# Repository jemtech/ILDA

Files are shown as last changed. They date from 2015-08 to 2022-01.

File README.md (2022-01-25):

# ILDA
This project is a DAC ([digital to analog converter](https://en.wikipedia.org/wiki/Digital-to-analog_converter)) which generates six [differential signals](https://en.wikipedia.org/wiki/Differential_signaling) based on the ILDA ([International Laser Display Association](http://www.laserist.org/)) [ISP-DB25 standard](http://www.laserist.org/StandardsDocs/ILDA_ISP99_rev002.pdf).
Two signals for the X and Y axis (-10V to +10V), four signals for the channels red, green and blue and one custom colour (0V to +5V).
The DAC is controlled via [SPI](https://en.wikipedia.org/wiki/Serial_Peripheral_Interface_Bus). In this case the software is written for a "Raspberry Pi", but any other controller can be used.

This project contains two sections:

1. Hardware: In this section you find a 16bit 6ch DAC for ILDA. Reaching 22kpps (measured with [ILDA Test Pattern](http://www.laserist.org/StandardsDocs/ILDA_TestPattern95_rev002.pdf), theoretical up to 400kpps) limited by the controling "Raspberry Pi". It is resulting in a resolution of 4294967296 positions (~4295 megapixels).
The asynchronous LDAC update pin at the DAC, immediately updates the DAC register with the contents of the input register, so all outputs change at the same time and can be synchronised with an external clock.
2. Software: C based software to control the ILDA-DAC with a "Raspberry Pi". Supports all Files based on the [ILDA Image Data Transfer Format](http://www.laserist.org/StandardsDocs/ILDA_IDTF14_rev011.pdf).

## Hardware
The hardware is designed with [KiCad](http://kicad.org/).
"ILDA/hardware/kicad/"
Using 5 channels (x,y,r,g,b) with 16bit at 50MHz SPI speed the DAC reaches theoretically 400kpps (50000KHz ÷ (5×24bit) = 416kpps).

## Software
### Dependencies
[Wiring Pi](http://wiringpi.com/).
### Installation
1. Install "Wiring Pi". Then follow the instructions on [Wiring Pi](http://wiringpi.com/).
2. Download this project to your "Raspberry Pi".
3. Change to the "ILDA/software/raspberrypi/" folder.
4. Run "make".

Now you can run the software with "sudo ./ildaNode".

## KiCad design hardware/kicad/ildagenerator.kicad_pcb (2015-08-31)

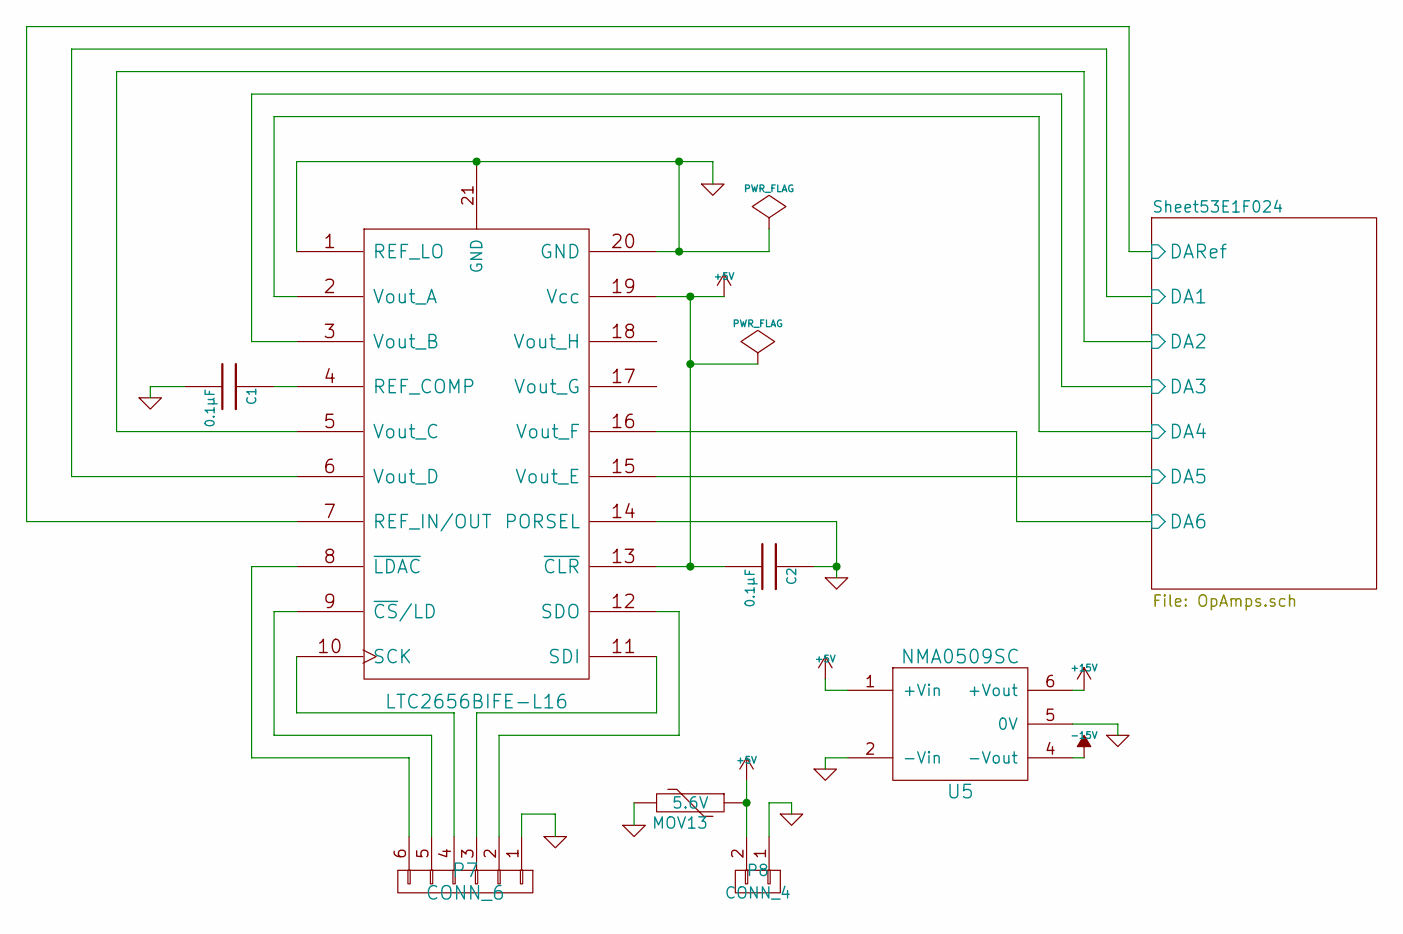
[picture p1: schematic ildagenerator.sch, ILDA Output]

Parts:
C1, C2: 0.1µF; C_0805_HandSoldering
MOV13: 5.6V; R_1206_HandSoldering
P7: CONN_6; Pin_Header_Straight_1x06
P8: CONN_4; Pin_Header_Straight_1x02
U1: LTC2656BIFE-L16
U5: NMA0509SC; NMA_5V_12V_15V_Series

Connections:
+5V: C2.2, MOV13.1, P8.2, U1.13 (~CLR), U1.19 (Vcc), U5.1 (+Vin)
+15V: U5.6 (+Vout); also elsewhere on the board
-15V: U5.4 (-Vout); also elsewhere on the board
/Sheet53E1F024/DA1: U1.6 (Vout_D); also elsewhere on the board
/Sheet53E1F024/DA2: U1.5 (Vout_C); also elsewhere on the board
/Sheet53E1F024/DA3: U1.3 (Vout_B); also elsewhere on the board
/Sheet53E1F024/DA4: U1.2 (Vout_A); also elsewhere on the board
/Sheet53E1F024/DA5: U1.15 (Vout_E); also elsewhere on the board
/Sheet53E1F024/DA6: U1.16 (Vout_F); also elsewhere on the board
/Sheet53E1F024/DARef: U1.7 (REF_IN/OUT); also elsewhere on the board
GND: C1.2, C2.1, MOV13.2, P7.1, P8.1, U1.1 (REF_LO), U1.14 (PORSEL), U1.20 (GND), U1.21 (GND), U5.2 (-Vin), U5.5 (0V); also elsewhere on the board
unnamed: C1.1, U1.4 (REF_COMP)
unnamed: P7.2, U1.12 (SDO)
unnamed: P7.3, U1.11 (SDI)
unnamed: P7.4, U1.10 (SCK)
unnamed: P7.5, U1.9 (~CS~/LD)
unnamed: P7.6, U1.8 (~LDAC)

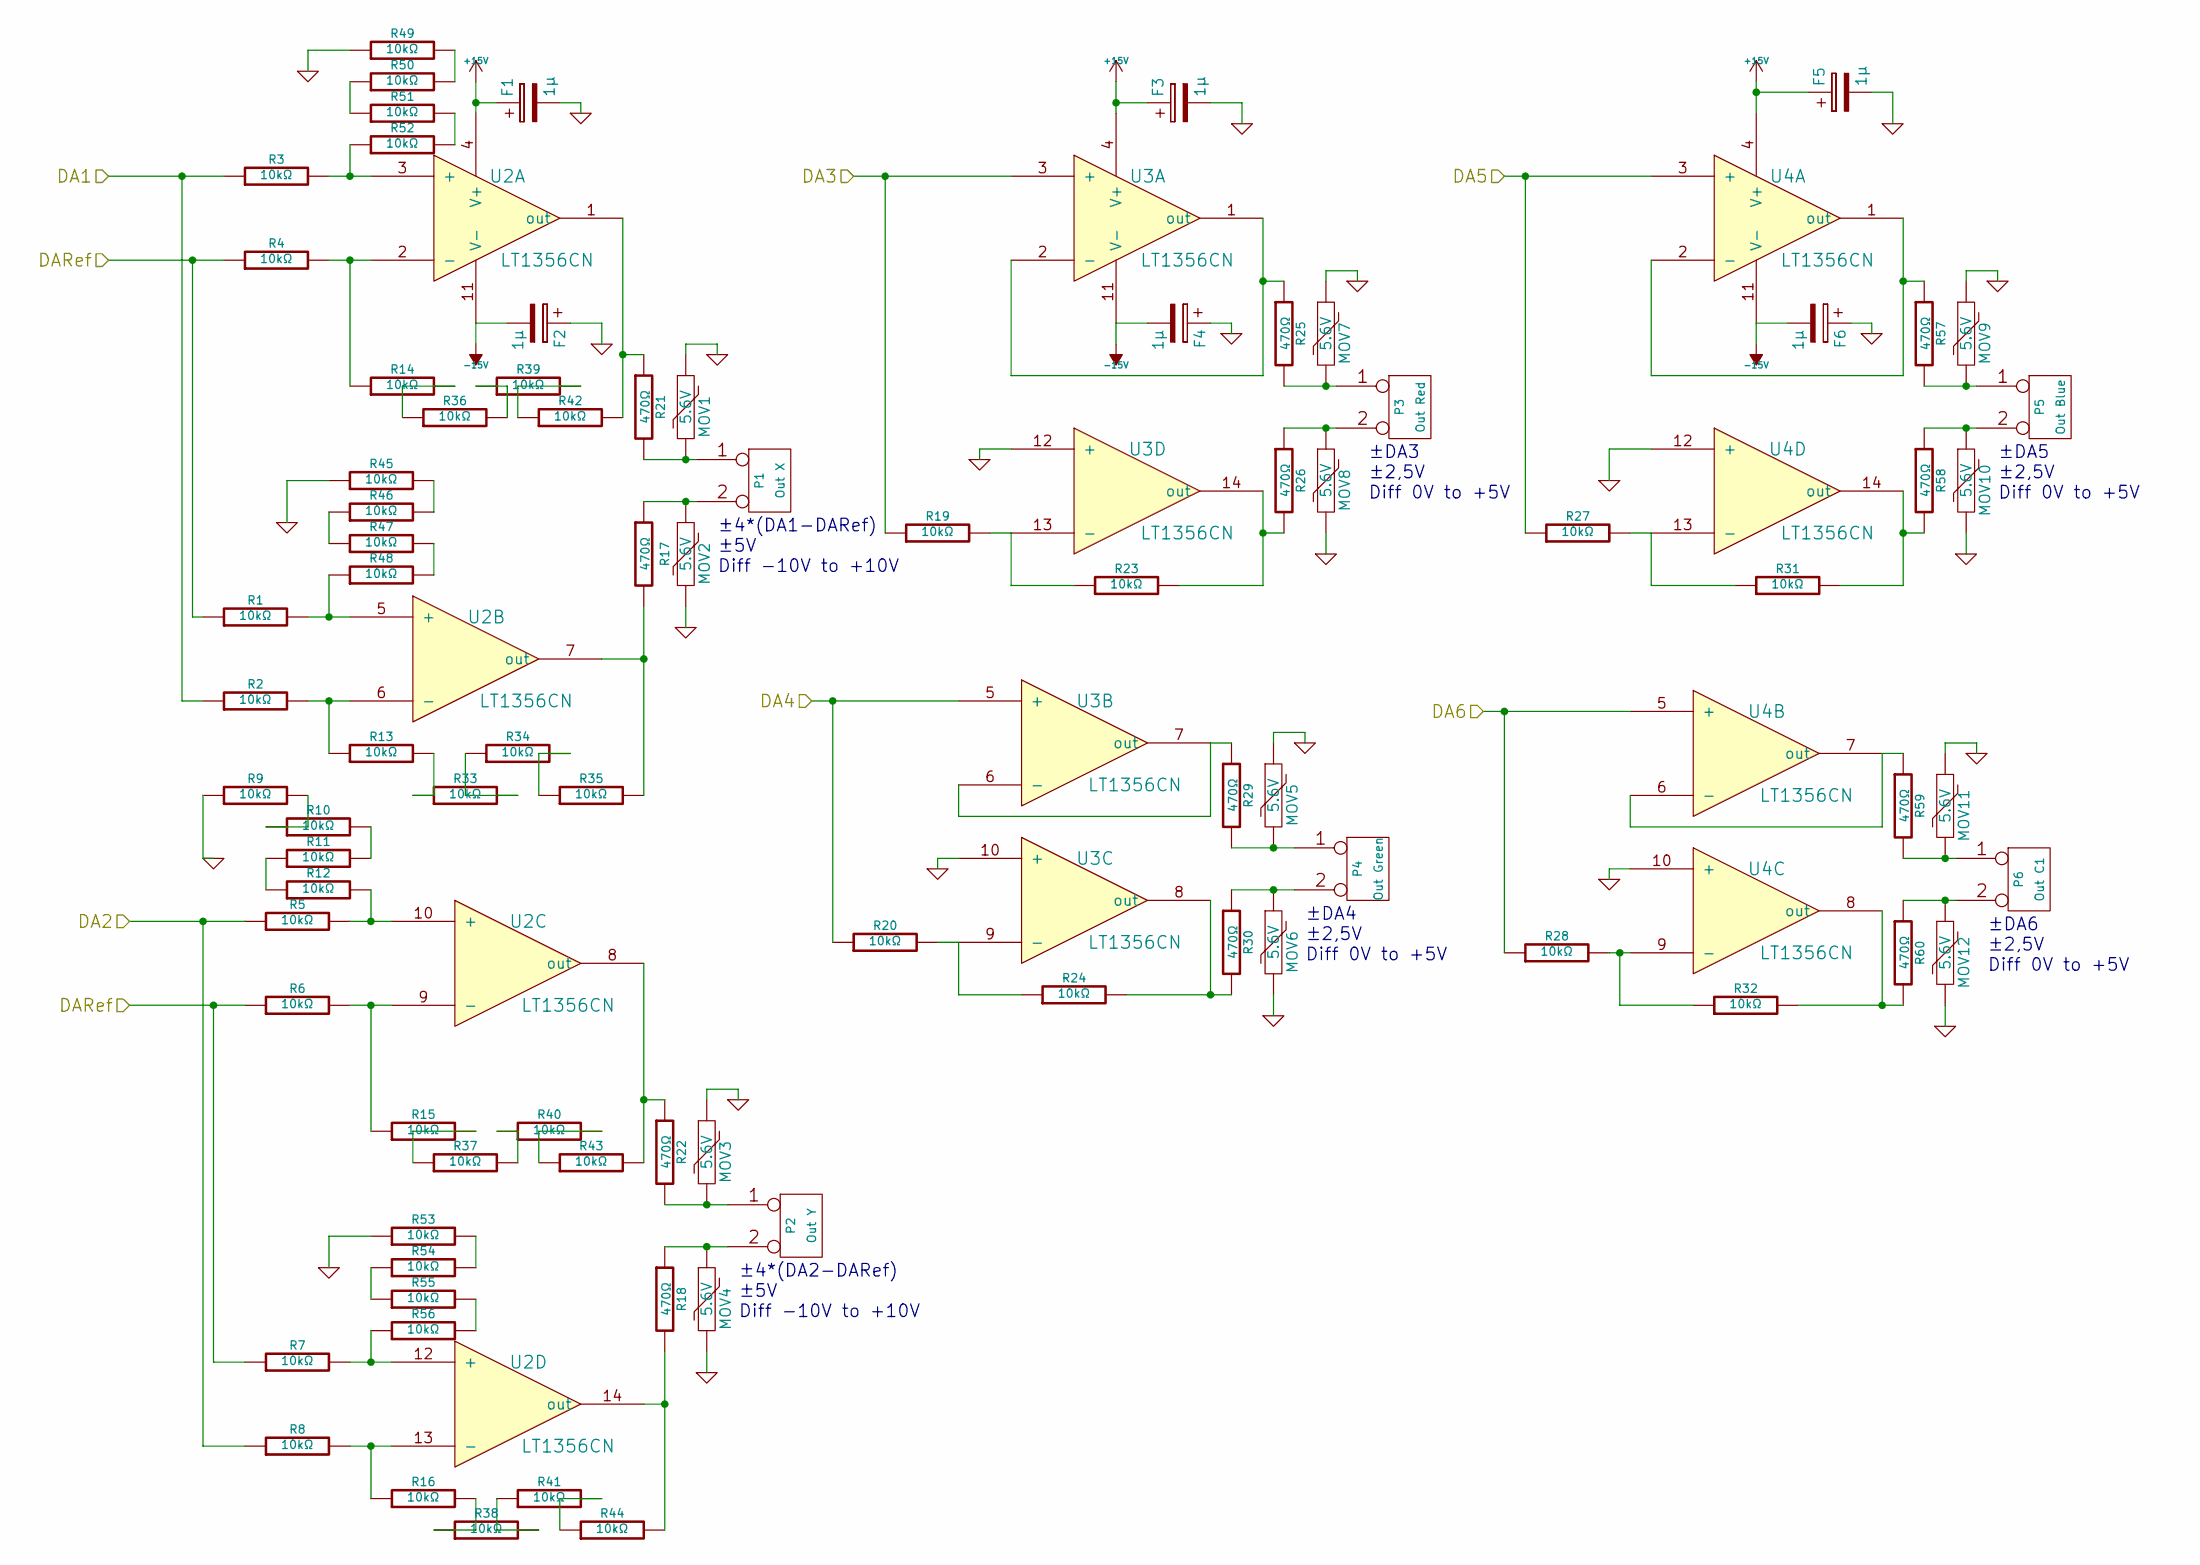
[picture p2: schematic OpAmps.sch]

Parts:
F1, F2, F3, F4, F5, F6: 1µ; TantalC_SizeB_EIA-3528_HandSoldering
MOV1, MOV2, MOV3, MOV4, MOV5, MOV6, MOV7, MOV8, MOV9, MOV10, MOV11, MOV12: 5.6V; R_1206_HandSoldering
P1: Out X
P2: Out Y
P3: Out Red
P4: Out Green
P5: Out Blue
P6: Out C1
R1, R2, R3, R4, R5, R6, R7, R8, R9, R10, R11, R12, R13, R14, R15, R16, R20, R24, R33, R34, R35, R36, R37, R38, R39, R40, R41, R42, R43, R44, R45, R46, R47, R48, R49, R50, R51, R52, R53, R54, R55, R56: 10kΩ; R_0603_HandSoldering
R17, R18, R21, R22: 470Ω; R_0603_HandSoldering
R19, R23, R27, R28, R31, R32: 10kΩ
R25, R26, R29, R30, R57, R58, R59, R60: 470Ω
U2, U3, U4: LT1356CN

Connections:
+15V: F1.1, F3.1, F5.1, U2.4 (V+), U3.4 (V+), U4.4 (V+); also elsewhere on the board
-15V: F2.2, F4.2, F6.2, U2.11 (V-), U3.11 (V-), U4.11 (V-); also elsewhere on the board
/Sheet53E1F024/DA1: R2.1, R3.1; also elsewhere on the board
/Sheet53E1F024/DA2: R5.1, R8.1; also elsewhere on the board
/Sheet53E1F024/DA3: R19.1, U3.3 (+); also elsewhere on the board
/Sheet53E1F024/DA4: R20.1, U3.5 (+); also elsewhere on the board
/Sheet53E1F024/DA5: R27.1, U4.3 (+); also elsewhere on the board
/Sheet53E1F024/DA6: R28.1, U4.5 (+); also elsewhere on the board
/Sheet53E1F024/DARef: R1.1, R4.1, R6.1, R7.1; also elsewhere on the board
GND: F1.2, F2.1, F3.2, F4.1, F5.2, F6.1, MOV1.1, MOV2.2, MOV3.1, MOV4.2, MOV5.1, MOV6.2, MOV7.1, MOV8.2, MOV9.1, MOV10.2, MOV11.1, MOV12.2, R9.1, R45.1, R49.1, R53.1, U3.10 (+), U3.12 (+), U4.10 (+), U4.12 (+); also elsewhere on the board
unnamed: MOV1.2, P1.1, R21.2
unnamed: MOV2.1, P1.2 (PM), R17.1
unnamed: MOV3.2, P2.1, R22.2
unnamed: MOV4.1, P2.2 (PM), R18.1
unnamed: MOV5.2, P4.1, R29.2
unnamed: MOV6.1, P4.2 (PM), R30.1
unnamed: MOV7.2, P3.1, R25.2
unnamed: MOV8.1, P3.2 (PM), R26.1
unnamed: MOV9.2, P5.1, R57.2
unnamed: MOV10.1, P5.2 (PM), R58.1
unnamed: MOV11.2, P6.1, R59.2
unnamed: MOV12.1, P6.2 (PM), R60.1
unnamed: R1.2, R48.1, U2.5 (+)
unnamed: R3.2, R52.1, U2.3 (+)
unnamed: R9.2, R10.1
unnamed: R10.2, R11.2
unnamed: R11.1, R12.1
unnamed: R5.2, R12.2, U2.10 (+)
unnamed: R2.2, R13.1, U2.6 (-)
unnamed: R13.2, R33.1
unnamed: R4.2, R14.1, U2.2 (-)
unnamed: R14.2, R36.1
unnamed: R6.2, R15.1, U2.9 (-)
unnamed: R15.2, R37.1
unnamed: R8.2, R16.1, U2.13 (-)
unnamed: R16.2, R38.1
unnamed: R17.2, R35.2, U2.7 (out)
unnamed: R18.2, R44.2, U2.14 (out)
unnamed: R19.2, R23.1, U3.13 (-)
unnamed: R20.2, R24.1, U3.9 (-)
unnamed: R21.1, R42.2, U2.1 (out)
unnamed: R22.1, R43.2, U2.8 (out)
unnamed: R23.2, R26.2, U3.14 (out)
unnamed: R24.2, R30.2, U3.8 (out)
unnamed: R25.1, U3.1 (out), U3.2 (-)
unnamed: R27.2, R31.1, U4.13 (-)
unnamed: R28.2, R32.1, U4.9 (-)
unnamed: R29.1, U3.6 (-), U3.7 (out)
unnamed: R31.2, R58.2, U4.14 (out)
unnamed: R32.2, R60.2, U4.8 (out)
unnamed: R33.2, R34.1
unnamed: R34.2, R35.1
unnamed: R36.2, R39.1
unnamed: R37.2, R40.1
unnamed: R38.2, R41.1
unnamed: R39.2, R42.1
unnamed: R40.2, R43.1
unnamed: R41.2, R44.1
unnamed: R45.2, R46.2
unnamed: R46.1, R47.1
unnamed: R47.2, R48.2
unnamed: R49.2, R50.2
unnamed: R50.1, R51.1
unnamed: R51.2, R52.2
unnamed: R53.2, R54.2
unnamed: R54.1, R55.1
unnamed: R55.2, R56.2
unnamed: R7.2, R56.1, U2.12 (+)
unnamed: R57.1, U4.1 (out), U4.2 (-)
unnamed: R59.1, U4.6 (-), U4.7 (out)

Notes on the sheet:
±4*(DA1-DARef) ±5V Diff -10V to +10V
±4*(DA2-DARef) ±5V Diff -10V to +10V
±DA3 ±2,5V Diff 0V to +5V
±DA4 ±2,5V Diff 0V to +5V
±DA5 ±2,5V Diff 0V to +5V
±DA6 ±2,5V Diff 0V to +5V

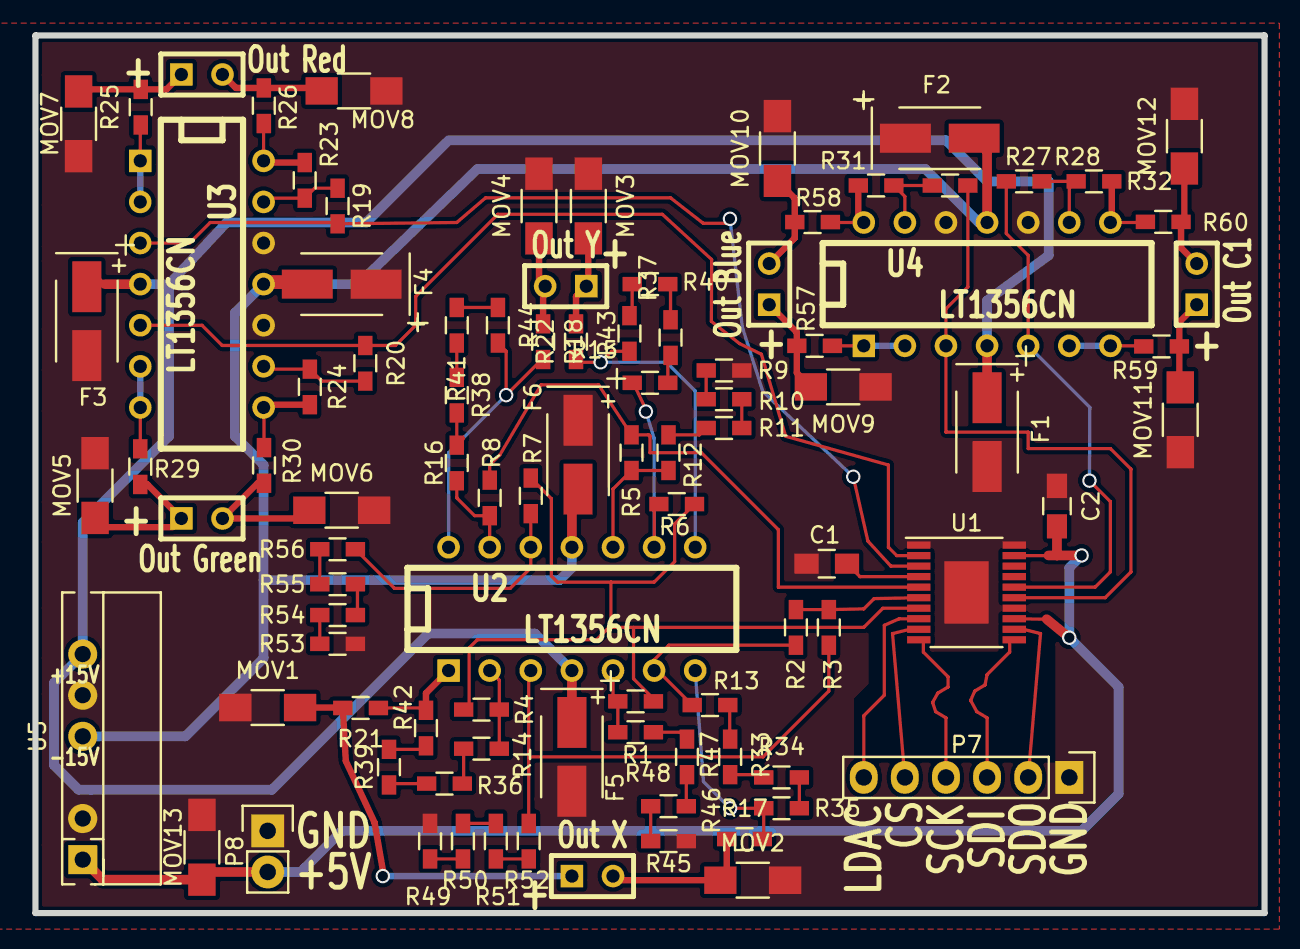
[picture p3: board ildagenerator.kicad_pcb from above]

Board: 2 copper layers, 75.9 x 54.2 mm, 94 parts (0 on the bottom side), 77 nets.

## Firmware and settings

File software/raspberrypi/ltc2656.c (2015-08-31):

#include <stdio.h>
#include <wiringPi.h>
#include <stdlib.h>
#include <fcntl.h>		//Needed for SPI port
#include <sys/ioctl.h>		//Needed for SPI port
#include <linux/spi/spidev.h>	//Needed for SPI port
#include <unistd.h>		//Needed for SPI port (close)
#include "ltc2656.h"

int spi_cs0_fd;			//file descriptor for the SPI device
int spi_cs1_fd;			//file descriptor for the SPI device


//SET SPI MODE
unsigned char SPI_MODE = SPI_MODE_0; //SPI_MODE_0 (0,0) CPOL = 0, CPHA = 0, Clock idle low, data is clocked in on rising edge, output data (change) on falling edge


//***********************************
//***********************************
//********** SPI OPEN PORT **********
//***********************************
//***********************************
//spi_device	0=CS0, 1=CS1
int SpiOpenPort (int spi_device)
{
    int status_value = -1;
    int *spi_cs_fd;
    
    if (spi_device)
    	spi_cs_fd = &spi_cs1_fd;
    else
    	spi_cs_fd = &spi_cs0_fd;


    if (spi_device)
    	*spi_cs_fd = open(SPIDEV_1_PATH, O_RDWR);
    else
    	*spi_cs_fd = open(SPIDEV_0_PATH, O_RDWR);

    if (*spi_cs_fd < 0)
    {
        perror("Error - Could not open SPI device");
        exit(1);
    }

    status_value = ioctl(*spi_cs_fd, SPI_IOC_WR_MODE, &SPI_MODE);
    if(status_value < 0)
    {
        perror("Could not set SPIMode (WR)...ioctl fail");
        exit(1);
    }

    status_value = ioctl(*spi_cs_fd, SPI_IOC_RD_MODE, &SPI_MODE);
    if(status_value < 0)
    {
      perror("Could not set SPIMode (RD)...ioctl fail");
      exit(1);
    }

	unsigned char bitsPerWord = SPI_BITS_PER_WORD;
    status_value = ioctl(*spi_cs_fd, SPI_IOC_WR_BITS_PER_WORD, &bitsPerWord);
    if(status_value < 0)
    {
      perror("Could not set SPI bitsPerWord (WR)...ioctl fail");
      exit(1);
    }

    status_value = ioctl(*spi_cs_fd, SPI_IOC_RD_BITS_PER_WORD, &bitsPerWord);
    if(status_value < 0)
    {
      perror("Could not set SPI bitsPerWord(RD)...ioctl fail");
      exit(1);
    }
	unsigned int spiSpeed = SPI_SPEED;
    status_value = ioctl(*spi_cs_fd, SPI_IOC_WR_MAX_SPEED_HZ, &spiSpeed);
    if(status_value < 0)
    {
      perror("Could not set SPI speed (WR)...ioctl fail");
      exit(1);
    }

    status_value = ioctl(*spi_cs_fd, SPI_IOC_RD_MAX_SPEED_HZ, &spiSpeed);
    if(status_value < 0)
    {
      perror("Could not set SPI speed (RD)...ioctl fail");
      exit(1);
    }
    return(status_value);
}

//************************************
//************************************
//********** SPI CLOSE PORT **********
//************************************
//************************************
int SpiClosePort (int spi_device)
{
	int status_value = -1;
    int *spi_cs_fd;

    if (spi_device)
    	spi_cs_fd = &spi_cs1_fd;
    else
    	spi_cs_fd = &spi_cs0_fd;


    status_value = close(*spi_cs_fd);
    if(status_value < 0)
    {
    	perror("Error - Could not close SPI device");
    	exit(1);
    }
    return(status_value);
}

//*******************************************
//*******************************************
//********** SPI WRITE & READ DATA **********
//*******************************************
//*******************************************
//data		Bytes to write.  Contents is overwritten with bytes read.
int SpiWriteAndRead (int spi_device, unsigned char *data, int length){
	struct spi_ioc_transfer spi[length];
	int i = 0;
	int retVal = -1;
	int *spi_cs_fd;

    if (spi_device)
    	spi_cs_fd = &spi_cs1_fd;
    else
    	spi_cs_fd = &spi_cs0_fd;

	//one spi transfer for each byte

	for (i = 0 ; i < length ; i++)
	{
		spi[i].tx_buf        = (unsigned long)(data + i); // transmit from "data"
		spi[i].rx_buf        = (unsigned long)(data + i) ; // receive into "data"
		spi[i].len           = sizeof(*(data + i)) ;
		spi[i].delay_usecs   = 0 ;
		spi[i].speed_hz      = SPI_SPEED ;
		spi[i].bits_per_word = SPI_BITS_PER_WORD ;
		spi[i].cs_change = 0;
		spi[i].pad = 0;
	}
	retVal = ioctl(*spi_cs_fd, SPI_IOC_MESSAGE(length), &spi) ;
	if(retVal < 0)
	{
		perror("Error - Problem transmitting spi data..ioctl");
		exit(1);
	}

	return retVal;
}

void setChVal(unsigned char channel, unsigned char valUpper, unsigned char valLower){
	unsigned char data[] = {channel, valUpper, valLower};
	SpiWriteAndRead(0, data, 3);
}

void setChVal_int(unsigned char channel, unsigned int val){
	setChVal(channel, (unsigned char)(val>>8), val & 0xff);
}

void setChVal_float(unsigned char channel, float val){
	setChVal_int(channel, val * 32768 + 32767);
}

void executeValues(){
	digitalWrite (LDAC_PIN, LOW);
	delayMicroseconds(1);
	digitalWrite (LDAC_PIN,  HIGH);
}

void initLtc2656(){
	wiringPiSetup ();
	pinMode (LDAC_PIN, OUTPUT);
	digitalWrite (LDAC_PIN,  HIGH);
	SpiOpenPort(SPI_DEV);
}

void closeLtc2656(){
	SpiClosePort(SPI_DEV);
}

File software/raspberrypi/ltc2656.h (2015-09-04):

#ifndef LTC2656_H
#define LTC2656_H
//GPOI pin for LDAC in wireingPi
static const int LDAC_PIN = 7; // = P4
//spi device 0=CS0, 1=CS1
static const int SPI_DEV = 0;
//SPI BUS SPEED
static const unsigned int SPI_SPEED = 50000000;//= 50MHz
//SET BITS PER WORD
static const unsigned char SPI_BITS_PER_WORD = 8;
static const char *SPIDEV_1_PATH = "/dev/spidev0.1";
static const char *SPIDEV_0_PATH = "/dev/spidev0.0";

void setChVal(unsigned char channel, unsigned char valUpper, unsigned char valLower);
void setChVal_int(unsigned char channel, unsigned int val);
void setChVal_float(unsigned char channel, float val);

void executeValues();
void initLtc2656();
void closeLtc2656();

#endif /*LTC2656_H*/

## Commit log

2015-08-25 hardware init
    [OpAmps.sch, ildagenerator.brd, ildagenerator.kicad_pcb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]
2015-08-27 add output protection
    [OpAmps.sch]
2015-08-27 rout output protection
    [OpAmps.sch, ildagenerator.kicad_pcb]
2015-08-28 mov output protect
    [OpAmps.sch, ildagenerator.kicad_pcb, ildagenerator.sch]
2015-08-29 placing movs
    [OpAmps.sch, ildagenerator.kicad_pcb]
2015-08-31 switch menue item
2015-08-31 onboard power dc/dc
    [OpAmps.sch, ildagenerator.kicad_pcb, ildagenerator.sch]
2015-08-31 correct socket
    [ildagenerator.kicad_pcb]
2021-11-08 Update README.md
    https://forum.kicad.info/t/warning-avoid-all-links-to-kicad-pcb-org-use-kicad-org/31521
